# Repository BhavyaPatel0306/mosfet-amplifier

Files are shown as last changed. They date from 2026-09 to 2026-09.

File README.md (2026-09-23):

# MOSFET Amplifier Design



**Four stages. A 3.3 V supply. A study in gain, bandwidth, power, and output headroom.**

An analog electronics project for **ELE404: Electronics I at Toronto Metropolitan University**, built in **KiCad 9** with the supplied NMOS models. Three common-source stages provide voltage gain; a common-drain stage buffers the output.

[Read the report](docs/project-report.pdf) · [Open the design](hardware/ELE404Project.kicad_pro) · [Reproduce the analysis](docs/SIMULATION.md) · [Results and limitations](docs/RESULTS.md)

Current committed KiCad schematic exported with KiCad 9.0.4

*Fresh export of the actual committed circuit. The original report illustrates a different revision; experimental changes are kept in a separate netlist.*

## What this project explores

- **Cascaded voltage gain:** distributing amplification across three common-source stages.
- **Independent DC biasing:** resistor dividers and interstage AC coupling.
- **Load driving:** using a source follower to reduce output impedance.
- **Engineering trade-offs:** balancing low power against output swing and clipping.

```mermaid
flowchart LR
    IN[AC input] --> CS1[Common-source 1]
    CS1 --> CS2[Common-source 2]
    CS2 --> CS3[Common-source 3]
    CS3 --> CD[Source follower]
    CD --> OUT[AC-coupled output]
    OUT --> LOAD[10 kohm / 2 pF load]
```

*Conceptual signal path described in the report; bias and bypass networks are omitted.*

## Fresh simulation evidence

**v0.2.0 includes actual ngspice 44 runs**, raw CSV data, a reproducible runner, and a separate experimental circuit.

- **Original circuit:** 64.82 dB loaded gain, approximately 14.29 MHz upper cutoff, and **1.0208 mW DC power**. Its 1.510 Vpp waveform at 1 mV peak input has **27.91% THD** and clips.
- **Experimental variant:** 61.16 dB loaded gain and **0.9201 mW DC power**. At 0.75 mV peak input it produces **1.568 Vpp with 4.00% THD**.

The variant is a measured improvement at the stated input amplitudes, **not a fully compliant replacement**. Gain-stage overdrive is below the guideline, transient follower current exceeds 200 uA, and clean-swing acceptance still needs a defined distortion limit. The original KiCad circuit is preserved.

Fresh loaded AC comparison

[Measured results and limits](docs/VERIFICATION.md) · [Repeat the runs](simulations/README.md) · [Historical report results](docs/RESULTS.md) · [Versioned releases](https://github.com/BhavyaPatel0306/mosfet-amplifier/releases)

## Get started

1. Download **Code → Download ZIP** and extract it, or clone the repository:

   ```sh
   git clone https://github.com/BhavyaPatel0306/mosfet-amplifier.git
   cd mosfet-amplifier
   ```

2. Open [`hardware/ELE404Project.kicad_pro`](hardware/ELE404Project.kicad_pro) in KiCad 9, then open the schematic.
3. Keep `hardware/models/` alongside the project. All four transistor model references use `models/nmos_t.txt`.
4. Follow the [simulation guide](docs/SIMULATION.md) before running the saved workbook.

**Verification status:** fresh ngspice DC/AC/transient runs and package checks are documented. GitHub Actions checks packaging, not electrical performance. No KiCad GUI/ERC validation or PCB layout validation is claimed; the PCB remains a placeholder.

## Repository guide

```text
mosfet-amplifier/
├── hardware/                 KiCad project, schematic, simulator workbook
│   └── models/               Supplied NMOS and PMOS models
├── docs/
│   ├── project-report.pdf    Original ten-page report
│   ├── design-guidelines.pdf Original assignment specifications
│   ├── SIMULATION.md         Setup and measurement procedure
│   ├── RESULTS.md            Evidence and limitations
│   ├── ROADMAP.md            Prioritized engineering improvements
│   └── images/               Figures extracted from the report
├── simulations/              Portable netlists, raw results, and comparison plots
├── originals/                Untouched project ZIP, including backups
├── scripts/verify_package.py File-integrity and model-reference checks
├── CONTRIBUTING.md           How to submit reproducible improvements
├── RECOVERY.md               Packaging provenance
└── SHA256SUMS.txt            Checksums for distributed files
```

Check the downloaded package with Python 3:

```sh
python scripts/verify_package.py
```

This checks hashes, model references, saved JSON files, and original archive integrity. **It does not simulate the amplifier.**

## Next design steps

The baseline is now simulated and documented. Next, resolve overdrive, distortion, and peak-current constraints before moving an experimental redesign into KiCad. See the [roadmap](docs/ROADMAP.md).

## Source material and reuse

The report, assignment, models, and original archive are preserved from the supplied materials. Images are extracted from that report. No new license has been applied; public visibility does not itself grant reuse rights to third-party course or model materials.

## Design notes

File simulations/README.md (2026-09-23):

# Reproducible circuit study

Two circuits are included: the actual exported KiCad baseline and a separate experimental SPICE variant. The variant is not incorporated into the KiCad schematic and is not a fully compliant replacement.

## Run

Install Python 3.11 or later, the dependencies in `requirements.txt`, and a shared ngspice library. These results used Python 3.12.14, NumPy 2.3.5, and the ngspice 44 DLL bundled with KiCad 9.0.4 on Windows. See `results/summary.json` for the recorded Python version, which is authoritative.

```sh
python -m pip install -r simulations/requirements.txt
python scripts/run_simulations.py --library /path/to/libngspice.so --output build/simulation-results
```

On Windows, the runner detects `C:/Program Files/KiCad/9.0/bin/ngspice.dll` if present. You can also specify `--library` or set `NGSPICE_LIBRARY`. Only the shared-library interface is used; a standalone ngspice executable is not required. No user settings or schematic files are changed by the runner.

The default run uses 27 C, ngspice `ps` compatibility, `reltol=1e-4`, an 80 ms transient with a 200 ns maximum time step, and a 200-point/decade AC sweep from 1 Hz to 100 MHz. It may take several minutes. Results are saved as CSV, JSON, and a simulator log. Plot generation is separate from simulation and is not needed to reproduce numeric results.

## Circuit definitions

- `netlists/baseline.cir`: exported by KiCad 9.0.4 from the committed schematic; only its model include was made relative. The saved source has AC magnitude zero. The runner records that zero-response case, then uses AC magnitude 1 to measure transfer gain. Transient input remains the saved 1 mV peak at 100 kHz.
- `netlists/candidate.cir`: experimental bias/degeneration variant. It adds a 50-ohm source resistor, moves the 2 pF load to the external output, raises R1/R6/R13 to 39 kohm, revises bias dividers, doubles Q3 width to 40 um, and adds a 4.7 kohm unbypassed source resistor at Q4. Input is 0.75 mV peak at 100 kHz.

The baseline gain-stage order is Q1 → Q2 → Q4, followed by follower Q3. This differs from the report's reference designators. Both circuits use the original NMOS model unchanged.

## Measurement definitions

AC output is `Net-_C6-Pad1_`, relative to ground, divided by the source's 1 V AC amplitude. For the candidate this includes the added source resistor. Gain and loaded/unloaded comparison are measured at 100 kHz. The upper cutoff is a 3 dB drop from that reference, interpolated in log frequency.

For the unloaded case, R10 is replaced by 1 Tohm rather than deleted, providing an effectively open DC reference for the output coupling capacitor. All capacitors are retained. Deleting R10 makes the original output float and gives invalid unloaded measurements.

DC power includes the complete supply current. Device current and overdrive are extracted from the internal BSIM transistor (`m.xqN.m0`). Overdrive here means the model's `VGS - VTH`; it is not the model's `VDSAT`. Reported DC branch currents are distinct from transient peak current.

The final 100 us window is compared with the 100 us window 20 ms earlier. THD is the root-sum-square of harmonics 2–10 divided by the fundamental, using a sinusoidal least-squares fit at 100 kHz on a uniformly interpolated trace. This finite-window estimate is not a laboratory distortion measurement or a formal timestep-convergence proof.

## Evidence and limits

Read [the measured results](../docs/VERIFICATION.md). These are fresh simulator runs, but not a claim that every assignment requirement is met. In particular, do not call the experimental waveform distortion-free. Component/process corners, temperature sweeps, GUI/ERC verification, and fabrication checks are outside this release.

The exact netlist, schematic, model, and runner hashes are recorded in `results/summary.json`. Raw data and commands are retained in `results/`. The GitHub Actions workflow checks package integrity and documentation; it does not run ngspice or certify electrical performance.

## References

- [KiCad command-line export documentation](https://docs.kicad.org/9.0/en/cli/cli.html)
- [ngspice shared-library interface](https://ngspice.sourceforge.io/shared.html)

## Regenerate plots

Install `reportlab==4.4.9` and run `python scripts/plot_results.py`. This renders the saved CSV data; it does not rerun ngspice. The simulator logs a missing `spinit` warning in this environment; the runner explicitly sets compatibility and numerical options, and no convergence errors were reported in the saved final run.

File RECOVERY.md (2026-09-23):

# Recovery and validation

The previous `/mnt/data/mosfet-amplifier-github.zip` was unavailable in the current desktop environment. This is a newly reconstructed package from the five recovered conversation attachments, not a byte-for-byte recovery of the missing generated ZIP.

The original project ZIP passed Python zipfile CRC validation. Its complete original bytes are preserved under originals/. Active project files were copied from its top-level project. Only four Sim.Library paths were changed in the active schematic, from an absolute Downloads path to models/nmos_t.txt. Circuit values, project configuration, and workbook analysis settings were not altered. Local locks, preferences, and historical backups are retained only inside the original ZIP.

Both PDFs and model files were copied byte-for-byte. The report and guidelines were inspected by text extraction. No simulation, KiCad GUI opening, electrical-rule check, or PCB validation was performed.

The rebuilt ZIP was checked for CRC errors, extracted into a fresh directory, and every extracted file was compared byte-for-byte to the staged package. A SHA-256 checksum accompanies the downloadable ZIP.

## Repository presentation update

The README and supporting guides were expanded, three historical report figures were extracted, and a Python package verifier was added. Original design files, PDFs, models, and archive are unchanged. The checksum manifest was regenerated for this edition. No new circuit simulations were run.

## v0.2.0 verification update

After the original recovery, fresh ngspice runs were completed. See docs/VERIFICATION.md and simulations/README.md. Earlier statements about no simulations describe the recovery stage only. The original schematic and models remain unchanged; the experimental variant is separate.

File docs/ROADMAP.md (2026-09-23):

# Engineering roadmap

## 1. Establish a reproducible baseline

Fresh runs, exact netlists, raw data, and a runner are now included in v0.2.0. The remaining task is full requirement coverage and model/operating-condition validation.

- Reconcile source settings and sweep range with the original report.
- Run DC, loaded and unloaded AC, and transient analyses with recorded versions and raw data.
- Map each assignment requirement to a measurement definition and result.

Completion means another reader can reproduce measurements from the committed circuit and recorded commands.

## 2. Investigate output swing

A separate variant now demonstrates 1.568 Vpp at 4.00% THD and 0.9201 mW DC power. Resolve its low gain-stage overdrive and transient current before promoting it to the KiCad project.

- Measure headroom, device currents, and clipping onset over input amplitude.
- Define a distortion criterion for acceptable swing.
- Evaluate bias changes and alternative output stages against the 1 mW power and 200 uA branch-current limits.

Completion means demonstrating at least 1.5 Vpp under the specified load and distortion criterion without violating another requirement.

## 3. Test robustness

- Sweep supply and temperature over explicitly selected ranges.
- Explore component and model variation where supported.
- Measure sensitivity to load resistance and capacitance.

Completion means documented sensitivity results and clearly identified supported conditions.

## 4. Consider physical implementation

The PCB is a placeholder. Physical implementation requires a separate technology and component plan, suitable models, layout, and validation. The supplied process-model simulation is not a ready-to-build discrete circuit.

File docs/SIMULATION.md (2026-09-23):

# Reproducing the analysis

Fresh automated runs are available in [VERIFICATION.md](VERIFICATION.md). Use the [reproducible runner](../simulations/README.md) to repeat them. The steps below describe manual inspection in KiCad.

## Open and inspect

1. Use KiCad 9, the version recorded in the schematic header. Other versions have not been tested here.
2. Open `hardware/ELE404Project.kicad_pro`, then its schematic.
3. Confirm the transistor library resolves to `hardware/models/nmos_t.txt` and the selected subcircuit is `nmos_3p3`.
4. Open the simulator and load `hardware/ELE404Project.wbk` if needed. It contains operating-point, AC, and transient setups.
5. Save experiments in a separate working copy or branch. Record KiCad and ngspice versions with the results.

## Known differences

The report and supplied project are not demonstrably the same simulation revision:

- The saved source is V2 with value `SINE(0 1m 100k)` and `Sim.Params` of `ac=0`. The report schematic shows V5, 1.45 mV peak at 100 kHz, and `ac=1`.
- The saved AC sweep is `.ac dec 100 1 10Meg`. The report describes 1 kHz to 100 MHz. A 10 MHz endpoint cannot establish a 20 MHz upper cutoff.
- The saved transient setup is `.tran 50n 100u 0 50n`. Confirm settling before measuring; extend the run if coupling or bypass capacitor startup is still visible.
- Saved traces refer to auto-generated node names. Check that each still maps to the intended input, interstage, or output node.

Reconcile these differences explicitly before claiming the report is reproduced. Original circuit settings have been preserved.

## DC operating point

Run `.op`. Record gate, drain, source, and bulk voltages, branch currents, and supply current. Check operating regions using actual model operating-point data where available. Calculate total power from supply voltage and current, accounting for the simulator's sign convention and including divider currents.

Compare against the guideline limits: 3.3 V supply, at most 1 mW total DC power, and at most 200 uA per branch.

## AC gain and bandwidth

Configure a nonzero small-signal AC magnitude, such as 1 V, in the source model editor. This AC normalization is separate from the small transient input amplitude.

Sweep beyond the expected cutoff; the report used 1 kHz to 100 MHz. Measure `V(out)/V(in)` and specify where input voltage is measured relative to the 50-ohm source resistor. Keep that definition consistent.

Find midband gain and the upper frequency where gain has dropped 3 dB from midband. Do not confuse this with an absolute gain of -3 dB. Extend the lower sweep when assessing the coupling-capacitor cutoff.

## Load sensitivity

Save separate loaded and unloaded configurations. State exactly which load elements change; the specified load is 10 kohm in parallel with 2 pF. Hold source settings, bias, and measurement frequency constant.

```text
gain reduction (%) = 100 × (1 − |A_loaded| / |A_unloaded|)
                   = 100 × (1 − 10^((G_loaded_dB − G_unloaded_dB)/20))
```

Do not calculate voltage-gain sensitivity by dividing a difference in dB by a dB value.

## Transient output swing

Start with a small sinusoid and sweep amplitude while staying within the 10 mVpp input limit. The report used 1.45 mV peak, or 2.9 mVpp, at 100 kHz.

After settling, inspect input and output, record output extrema, and check for flattened peaks or asymmetric clipping. Define a distortion criterion before calling the swing clean. A peak-to-peak measurement alone does not establish linear operation.

## Save reproducible evidence

Retain circuit revision, source settings, commands, simulator versions, load configuration, measurement definitions, raw exported data, and plots. Report failures and discrepancies alongside successful measurements.

See [RESULTS.md](RESULTS.md) for historical values and [ROADMAP.md](ROADMAP.md) for next steps.

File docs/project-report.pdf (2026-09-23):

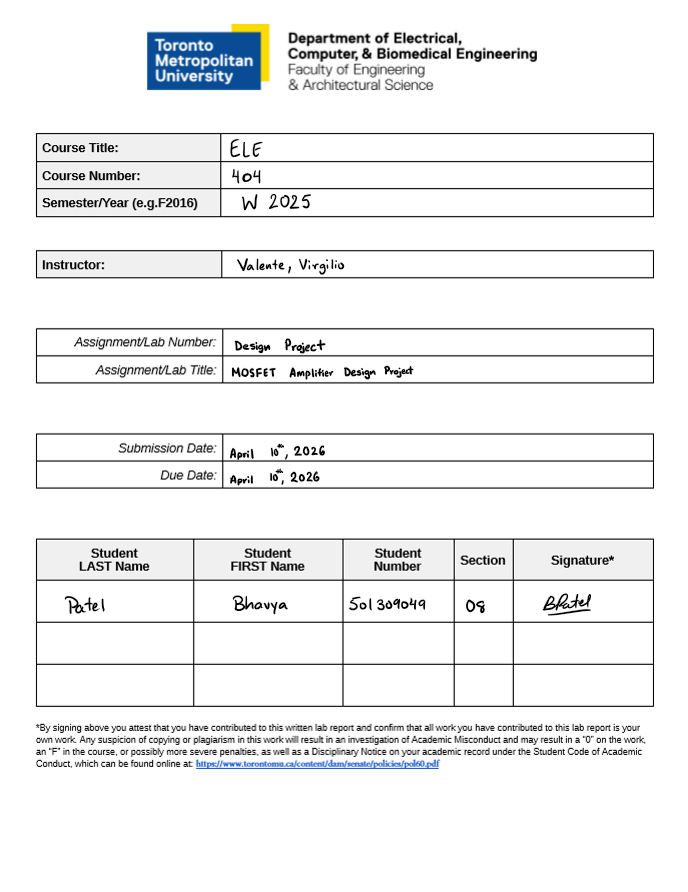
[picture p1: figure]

Introduction

This report details the design and simulation of an all-MOSFET, open-loop analog voltage amplifier developed using the Global Foundries 180nm CMOS process. To satisfy the project requirements, the circuit is engineered to deliver a minimum total voltage gain of 60 dB, a -3 dB bandwidth exceeding 500 kHz, and a maximum DC power consumption of 1 mW. The architecture consists of four NMOS transistor stages, featuring three cascaded Common-Source (CS) amplifiers for high gain followed by a Common-Drain (CD) source follower. This final stage acts as an output buffer, ensuring the amplifier can drive a 10 kΩ load without significant gain degradation.

Architecture Justification

The amplifier is constructed from four distinct NMOS stages designed to meet specific performance targets. The first stage (Q2) utilizes a Common-Source configuration to provide initial voltage gain; it incorporates a 280 kΩ bias divider network to exceed the 100 kΩ input resistance requirement and a 100 nF capacitor for AC coupling to block DC signals. The second (Q1) and third (Q3) stages are also AC-coupled Common-Source amplifiers cascaded to incrementally boost the signal until the total voltage gain reaches the target of at least 60 dB. Finally, the fourth stage (Q4) serves as a Common-Drain source follower that acts as an output buffer. While this final stage offers near-unity gain, its primary function is to significantly lower the output resistance, thereby isolating the preceding gain stages from the load and ensuring that gain reduction remains below 10% when driving a 10 kΩ load.

The selection of specific transistor topologies was driven by the need to balance high gain with effective load driving capabilities. The CS configuration was chosen for the first three stages because it offers superior voltage gain compared to other MOSFET setups. With a gain defined by |Av| = gm x (RD || ro), each stage contributes approximately 20–30 dB; when cascaded, these stages cumulatively reach the 60 dB target while remaining within the project's power and headroom limits.

For the final output stage, a Common-Drain (source follower) was implemented to provide a low output resistance, roughly equal to 1/gm. Although its voltage gain is slightly below unity (calculated at 0.71 V/V for this specific design), its low impedance is vital for driving the 10 kΩ load. This buffering effect minimizes the load's impact on the overall circuit, resulting in a load sensitivity of just 1.54%, which comfortably exceeds the maximum allowable 10% gain reduction specification.

All stage gains are below 40 dB, satisfying the per-stage gain constraint:

Stage | Transitor | Topology | Gain (V/V) | Gain dB
1 | Q2 | CS | 13.7 | 22.7
2 | Q1 | CS | 22.3 | 26.9

3 | Q3 | CS | 13.7 | 22.7
4 | Q4 | CD | 0.71 | -3.0

Calculations

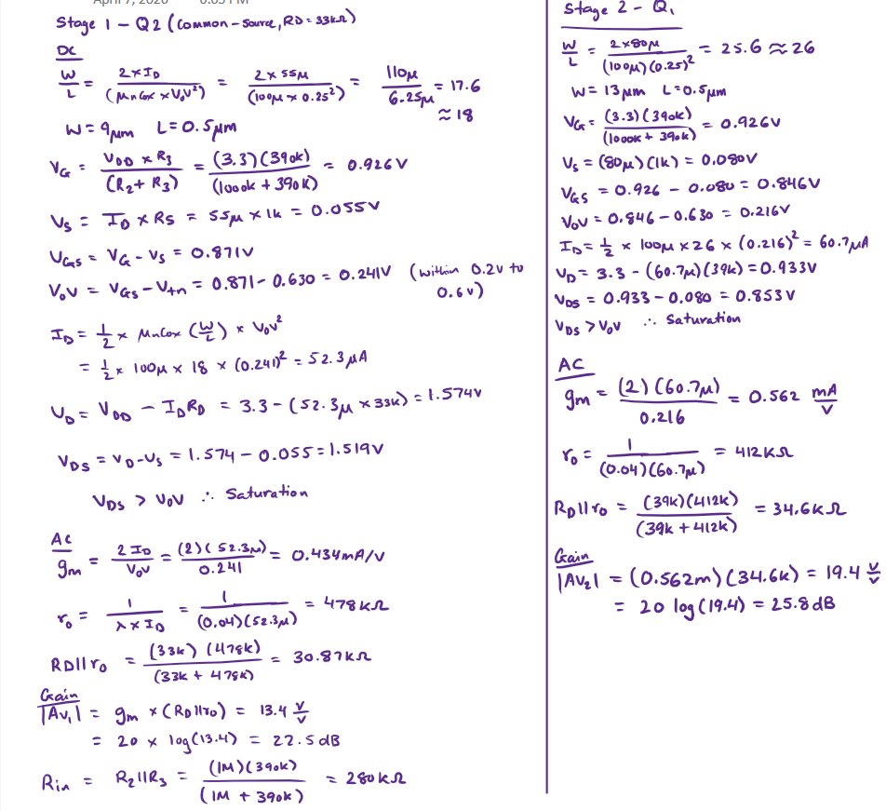
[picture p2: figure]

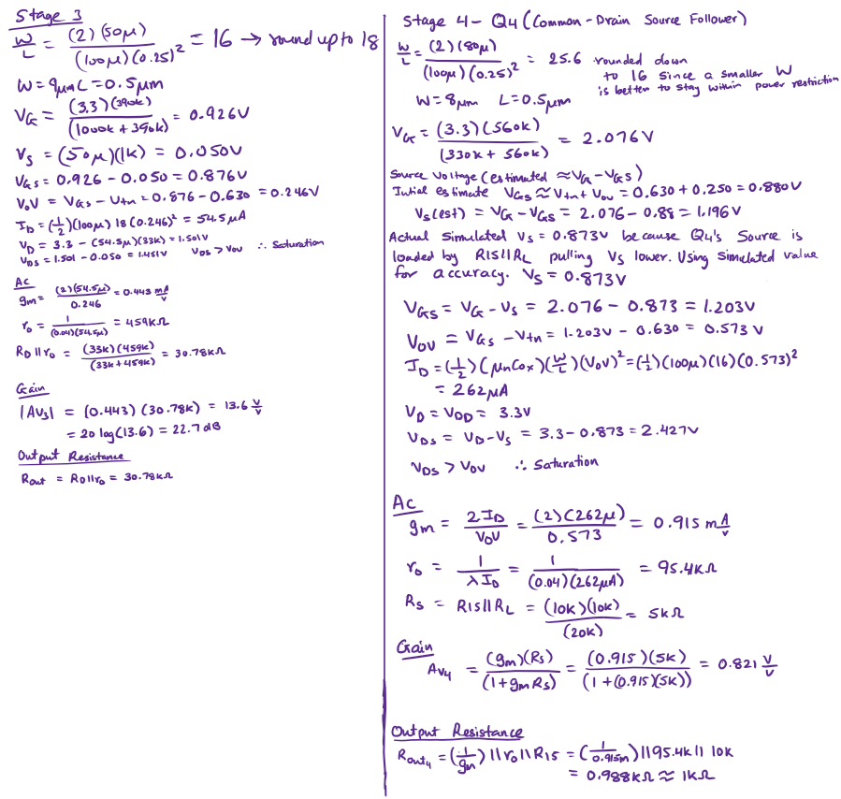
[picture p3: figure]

Biasing Strategy

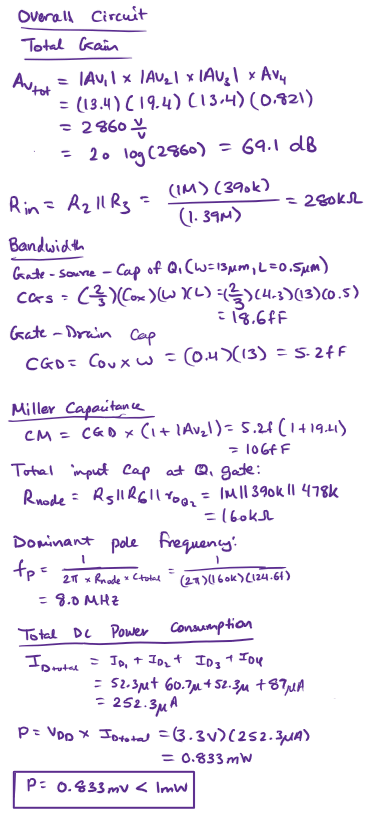
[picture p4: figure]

The biasing strategy for each Common-Source stage involves a resistor voltage divider to set a stable DC gate voltage, providing robustness against temperature and process shifts. To further enhance DC stability, a 1 kΩ source resistor (RS) is used to implement negative feedback. To prevent this resistor from causing source degeneration and lowering the AC voltage gain, a large 10 uF electrolytic bypass capacitor is added, effectively creating an AC short to ground. Furthermore, 100 nF AC coupling capacitors are utilized between stages to isolate DC bias levels; this allows each stage to be biased independently while ensuring the signal passes through the entire chain unimpeded.

Simulation Results

Schematic

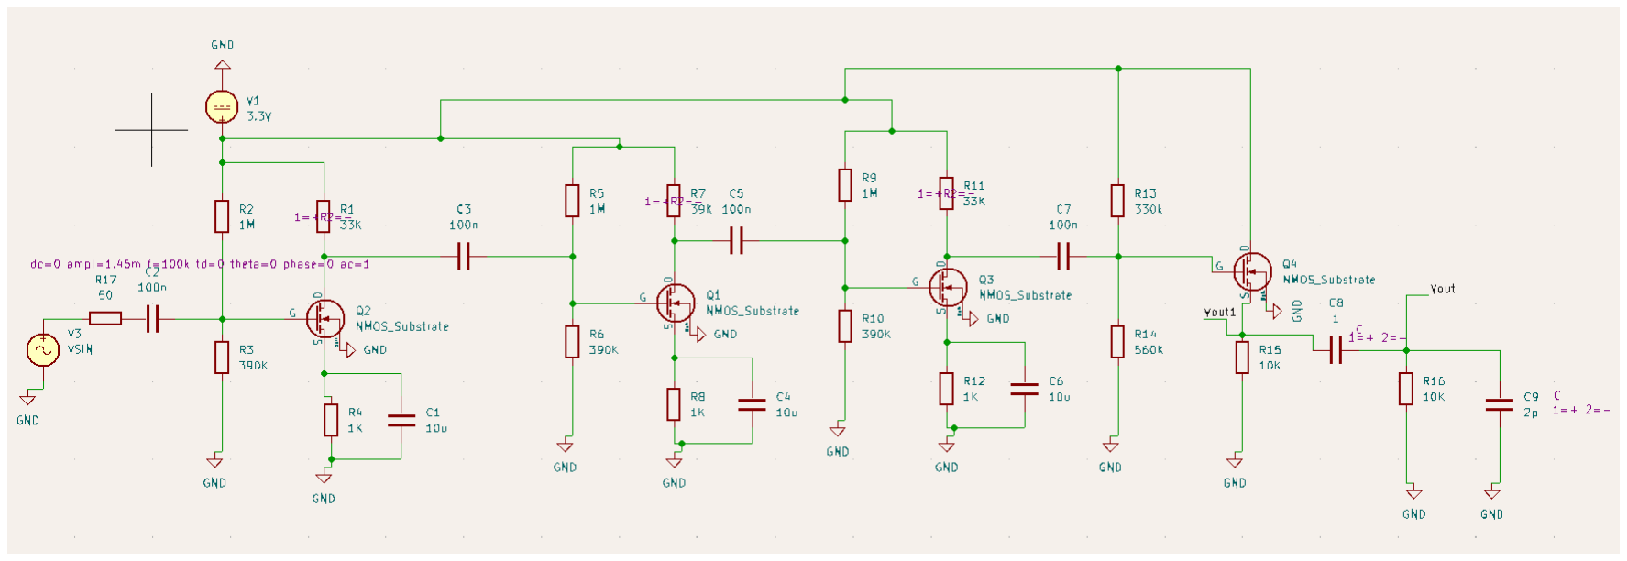
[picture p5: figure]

DC Operating Point

The DC operating point simulation was run to verify that all transistors are properly biased in the saturation region.

Transistor | VG (V) | VS(V) | VD(V) | VGS(V) | VDS(V)
Q2 | 0.926 | 0.048 | 1.729 | 0.878 | 1.681
Q1 | 0.926 | 0.058 | 1.044 | 0.868 | 0.986
Q3 | 0.926 | 0.048 | 1.729 | 0.878 | 1.681
Q4 | 2.076 | 0.873 | 3.300 | 1.203 | 2.427

To ensure proper linear amplification, every transistor in the design is biased within the saturation region, with the condition VDS > VOV confirmed for each device. The circuit draws a total supply current of 251 uA, resulting in an overall DC power dissipation of 0.828 mW. This performance figure successfully meets the project requirement of remaining under the 1 mW power limit.

AC Analysis

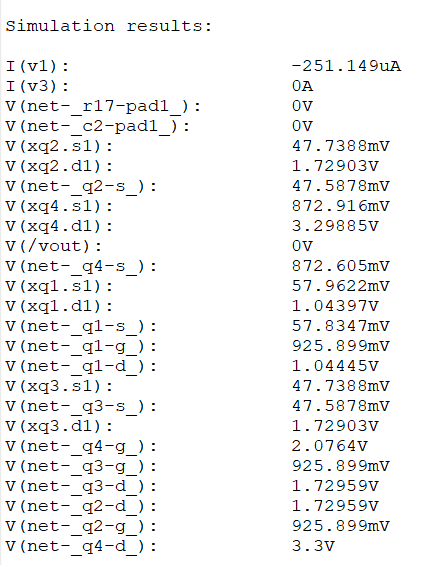
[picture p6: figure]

The AC small-signal analysis was performed with a frequency sweep from 1kHz to 100MHz (100 points per decade). The Bode plot of V(Vout)/V(Vin) in dB is shown below.

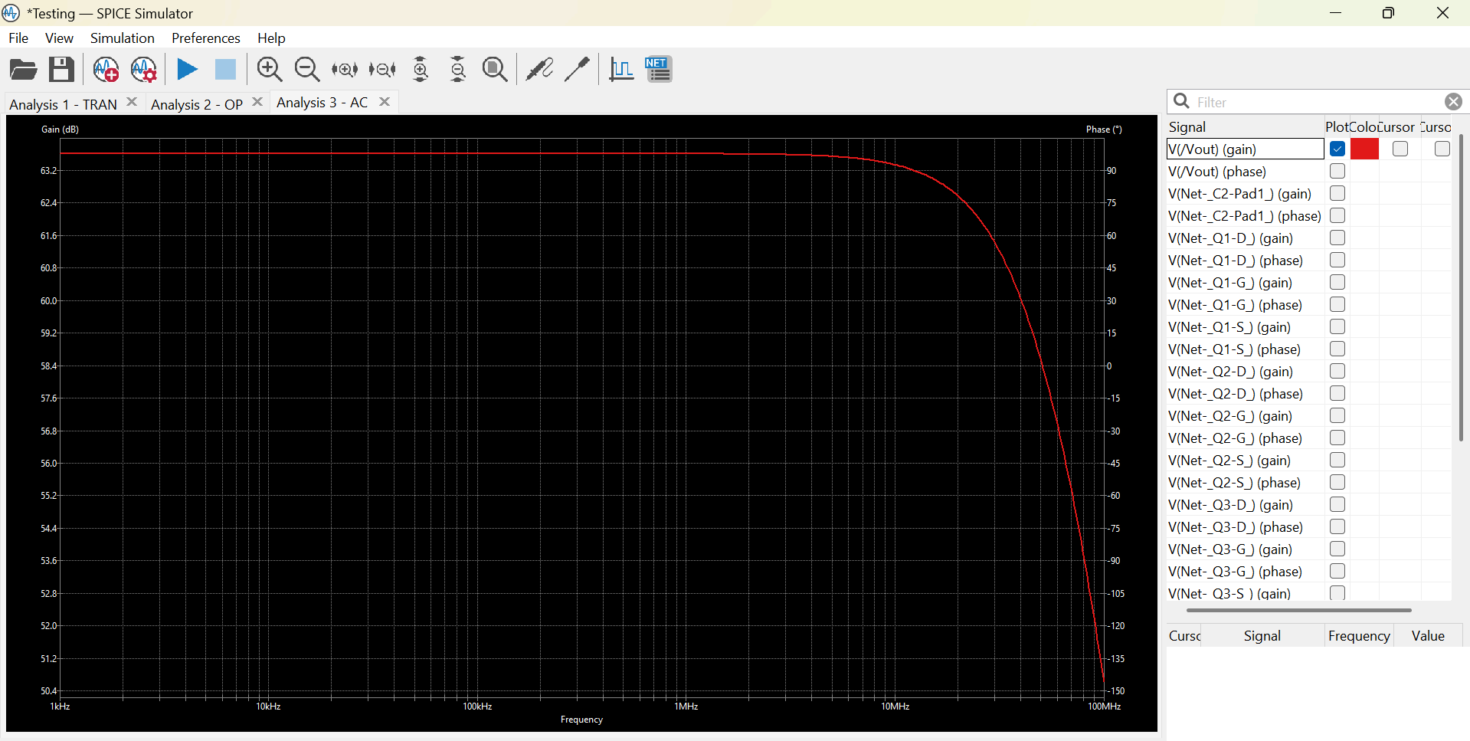
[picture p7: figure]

Parameter | Simulated Result
Midband gain (loaded) | 63.8 dB
Midband gain (unloaded) | 64.6 dB
-3 db Bandwidth | 20 MHz

Load Sensitivity | 1.54 % (dB)

The amplifier achieves a loaded midband gain of 63.8 dB, which comfortably surpasses the 60 dB design goal. Additionally, the -3 dB bandwidth reaches approximately 20 MHz, providing a substantial performance margin by exceeding the 500 kHz minimum requirement by a factor of 40. The unloaded gain was measured at 64.6 dB, indicating a load sensitivity of roughly 1.54%, a result that is well within the maximum allowable 10% specification.

Transient Analysis - Output Swing

A transient simulation was performed with a 100 kHz sinusoidal input of amplitude 1.45 mV (2.9 mVpp) to verify the output voltage swing.

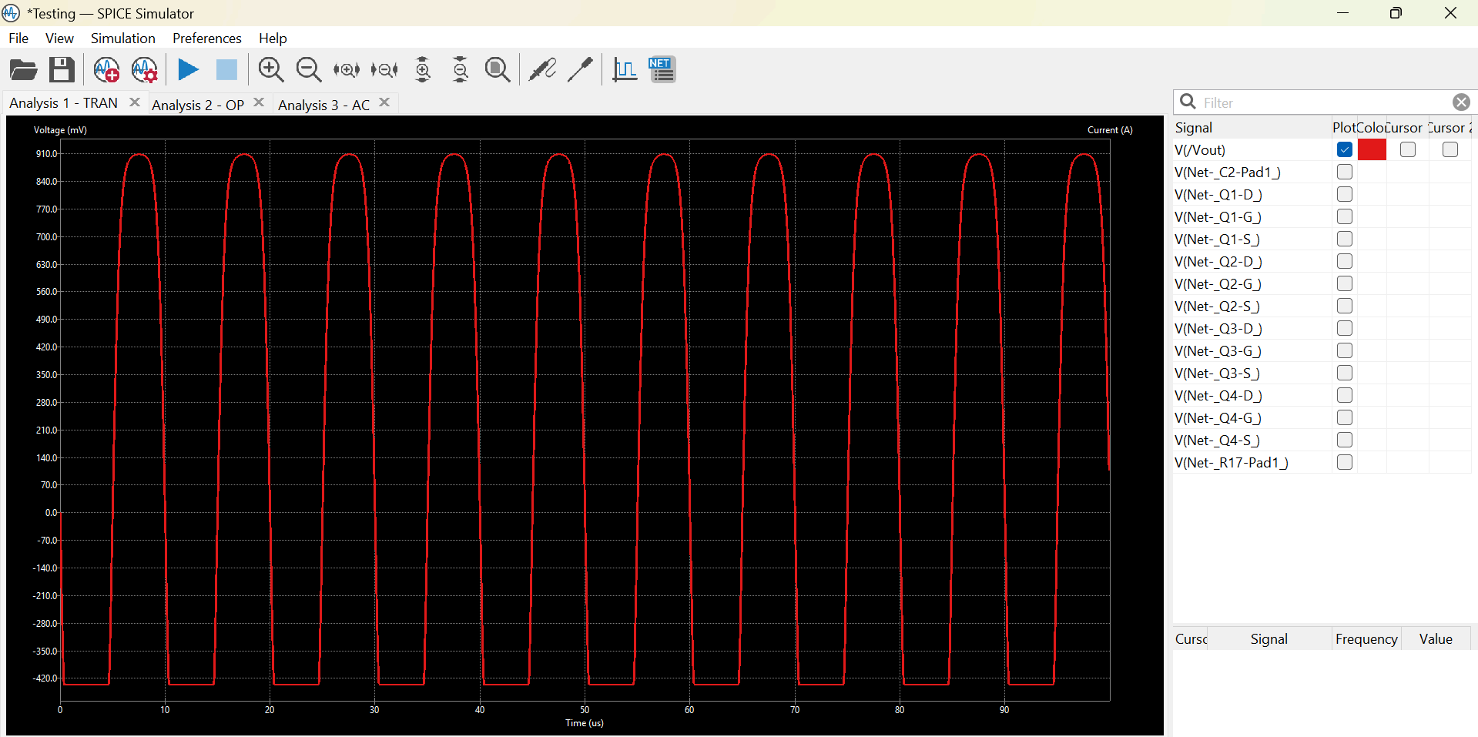
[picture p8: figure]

The output waveform demonstrates clear sinusoidal amplification. The positive half-cycle swings to +910 mV while the negative half-cycle is limited to approximately -420 mv before clipping occurs which makes the peak-to-peak swing to 1.33 Vpp.

Hand Calculations Vs Simulation

The hand calculations provide a reasonable first-order estimate of the circuit behaviour, with discrepancies in the expected range of 10-20% as stated in the design guidelines.

Parameter | Hand Calculation | Simulation | Discrepancy
Gate Voltage VG (Q2, Q3) | 0.926 V | 0.926 V | 1%
Drain Voltage VD (Q2,Q3) | 1.47 V | 1.729 V | 15%
Drain Current ID (Q2,Q3) | 55.4 uA | 52 uA | 6%
Total Gain | 69.5 dB | 63.8 dB | 8%

The gate voltage exhibits nearly perfect alignment because it is determined solely by the resistor divider network. However, the drain voltage shows a 15% discrepancy, which remains within expected limits; this variance arises because the simplified theoretical model does not account for second-order effects like the body effect and channel length modulation. Similarly, a total gain deviation of roughly 8% is observed, primarily due to inter-stage loading. While hand calculations typically treat each stage as an isolated entity, the physical cascading of these stages introduces finite output resistances that load subsequent stages, ultimately lowering the overall effective gain.

Output Swing

The simulation revealed that the output swing goal of 1.5 Vpp was not fully achieved, peaking at a clean maximum of approximately 1.33 Vpp. This shortfall is characterized by asymmetric clipping where the positive peak is larger than the negative, a common limitation of single-supply Common-Drain topologies. While the transistor Q4 can actively pull the output voltage up, it relies on the passive pull-down resistor (R15) to discharge the output node. During negative swings, as VGS approaches the threshold voltage, Q4 begins to cut off, leaving the parallel combination of R15 and RL (5 kΩ effective) unable to discharge the output capacitance quickly enough at 100 kHz.

To achieve a symmetric 1.5 Vpp swing, several design enhancements could be considered:

- Active Sourcing: Replace the passive resistor R15 with an active current source, such as a diode-connected NMOS, to improve sinking capability.
- Push-Pull Configuration: Transition to a CMOS push-pull output stage using complementary NMOS and PMOS transistors for balanced drive.
- Bias Adjustment: Shift the gate bias voltage of Q4 closer to the mid-rail to increase available headroom for both halves of the signal swing.

The design's total DC power consumption of 0.828 mW (at a total current of 251 µA) successfully meets the 1 mW limit with a 17% safety margin. Individual branch currents remained well under the 200 µA maximum, with Q1 drawing the highest current at approximately 80 µA. Ultimately, the strict power budget was the primary constraint limiting the drain bias current and, consequently, the maximum achievable transconductance (gm) in each stage.

Several design trade-offs were managed:
- Transistor Sizing: While increasing the transistor width (W) boosts gm and voltage gain, it simultaneously raises the drain current (ID), which increases power consumption and reduces drain voltage headroom. W values were specifically selected to balance these competing factors.
- Drain Resistance: The selection of drain resistors (RD) impacts both the DC operating point (VD = VDD - ID x RD) and AC gain (|Av| = gm x RD). Larger RD values enhance gain but lower VD, which restricts the output swing. The chosen values (33 kΩ for Q2/Q3 and 39 kΩ for Q1) reflect a calculated compromise to maintain high gain without sacrificing necessary voltage headroom.

Conclusion

A four-stage MOSFET voltage amplifier was successfully developed and simulated using the Global Foundries 180nm CMOS process. By cascading three Common-Source stages with a final Common-Drain source follower, the design achieved a loaded gain of 63.8 dB and an unloaded gain of 64.8 dB, both of which surpass the 60 dB target. Performance in other areas was also strong: the 20 MHz bandwidth far exceeded the 500 kHz minimum, and the total DC power consumption of 0.828 mW remained well under the 1 mW limit.

The only specification not entirely met was the output swing; the design produced a clean, undistorted output of 1.33 Vpp against the 1.5 Vpp requirement. This shortfall is attributed to the asymmetric drive limitations of a passive source follower output stage. To reach the full 1.5 Vpp target, replacing the pull-down resistor (R15) with an active current source is recommended.

Finally, manual calculations aligned with simulation results within a 10-20 range. The minor discrepancies primarily resulted from inter-stage loading and the use of simplified single-pole models for bandwidth estimation. Ultimately, this project illustrates the essential trade-offs between gain, bandwidth, power efficiency, and output swing inherent in MOSFET amplifier design.

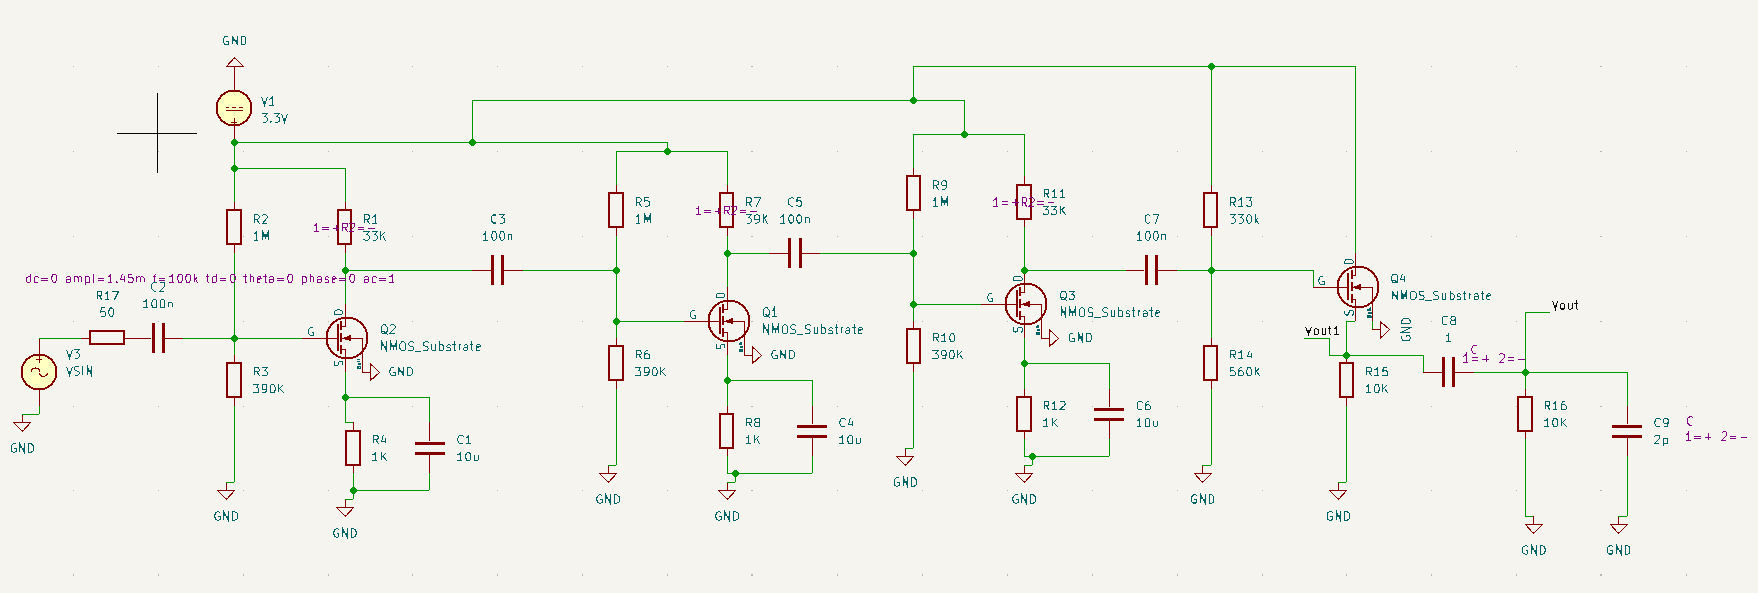
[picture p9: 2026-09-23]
docs/images/reported-schematic.png

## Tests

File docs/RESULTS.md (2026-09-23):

# Results, evidence, and limitations

**Fresh runs are now available:** see [v0.2.0 verification](VERIFICATION.md) and [raw results](../simulations/results/summary.json). The remainder of this page describes the historical report.

## Evidence boundary

The [original report](project-report.pdf) contains the author's simulation discussion and screenshots. Fresh runs of the supplied circuit give different results; see the verification link above. The [guidelines](design-guidelines.pdf) define the targets. Both PDFs remain unchanged.

## Historical report values

- **Loaded gain:** 63.8 dB, report page 7.
- **Unloaded gain:** 64.6 dB, page 7; target at least 60 dB.
- **Upper -3 dB bandwidth:** approximately 20 MHz, page 7; target at least 500 kHz. The current saved sweep stops at 10 MHz, so a new run needs a wider range.
- **DC power:** 0.828 mW at a reported 251 uA total current, page 6; limit 1 mW.
- **Output swing:** approximately 1.33 Vpp, pages 8–9; target at least 1.5 Vpp. The figure shows clipping, so it does not establish a clean 1.33 Vpp swing.

Other requirements, including input resistance, per-stage gain, sizing, overdrive, and maximum branch current, require consistent fresh verification before claiming full compliance.

## Load-sensitivity correction

The report lists 1.54% load sensitivity. Percent voltage-gain reduction must use linear gains, not percentage changes in dB values. From the rounded reported gains:

```text
100 × (1 − 10^((63.8 − 64.6)/20)) ≈ 8.80%
```

This is arithmetic on reported numbers, not a new measurement. It is below the 10% limit if the gains are reproduced under comparable conditions.

## Output-stage limitation

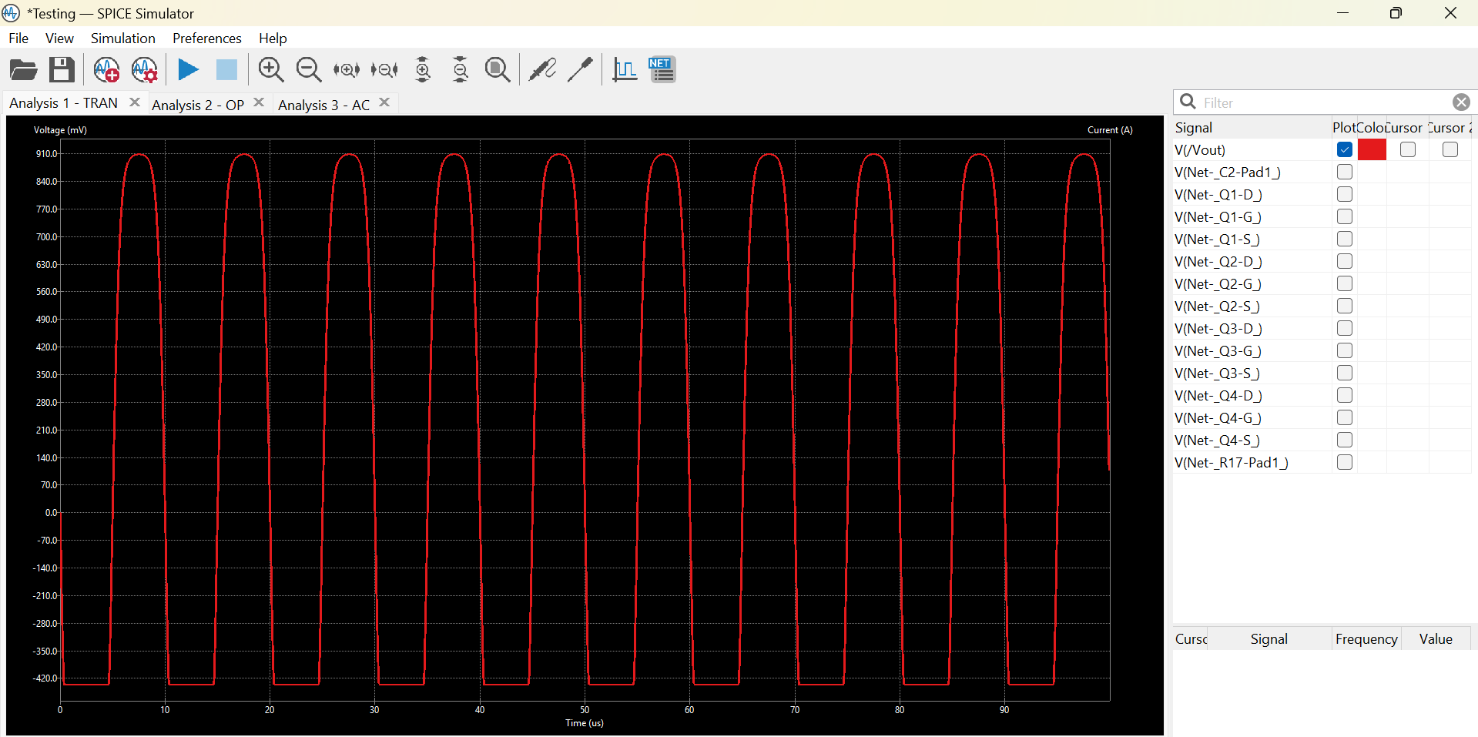
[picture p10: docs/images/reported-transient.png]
Transient plot from report page 8 showing asymmetric clipping


The output has a flattened negative excursion. Investigate device operating points and transient currents before selecting a redesign. The existing evidence does not establish a distortion-qualified output swing.

## Figure provenance

- `images/reported-schematic.png`: embedded schematic, report page 6.
- `images/reported-ac-response.png`: embedded AC plot, report page 7.
- `images/reported-transient.png`: embedded transient plot, report page 8.

Figures were extracted without redrawing the circuit or regenerating curves. They show the report revision, which differs from the supplied project in source settings and sweep range. See [SIMULATION.md](SIMULATION.md#known-differences).

## Verification scope

File hashes, original ZIP CRC, relative model references, and KiCad project/workbook JSON parsing are package checks. They do not demonstrate circuit correctness, model compatibility, fabrication readiness, or simulation success by themselves. The separately documented ngspice runs provide the fresh simulation evidence.

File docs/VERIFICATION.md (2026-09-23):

# Fresh simulation results — v0.2.0

These results were actually run with **ngspice 44**, using a **KiCad 9.0.4 export** and the supplied model files. They supersede assumptions that the original report describes the committed circuit. Full settings, hashes, CSV data, and logs are available in [simulations/](../simulations/README.md).

## Original KiCad circuit

- DC supply power: **1.0208 mW**, above the **1 mW** maximum.
- Gain at 100 kHz: **64.82 dB loaded**, **65.67 dB unloaded** with a 1 Tohm DC output reference.
- Upper cutoff relative to the 100 kHz gain: approximately **14.29 MHz**.
- Load-related voltage-gain reduction: approximately **9.34%**.
- At the saved **1 mV peak, 100 kHz** input: approximately **1.510 Vpp**, with **27.91% THD** over harmonics 2–10. This is clipped output, not a successful clean-swing result.
- Follower drain-current peak in the final transient window: approximately **288 uA**; its minimum approaches zero, consistent with cutoff.

The saved AC source magnitude is **zero** and produces zero AC response. Only the AC transfer-function measurement overrides it to 1. The original schematic is preserved.

The baseline also lacks the specified 50-ohm input source resistor and places its 2 pF capacitor before the output coupling capacitor. Its gain-stage overdrives, using model VGS minus VTH, are approximately **0.045 V, 0.144 V, and 0.144 V**, below the guideline's 0.2 V lower bound.

## Experimental variant

- DC supply power: **0.9201 mW**.
- Gain at 100 kHz: **61.16 dB loaded**, **61.69 dB unloaded**.
- Upper cutoff relative to the 100 kHz gain: approximately **11.02 MHz**.
- Load-related voltage-gain reduction: approximately **5.91%**.
- At **0.75 mV peak, 100 kHz** input: approximately **1.568 Vpp**, with **4.00% THD** over harmonics 2–10.
- Follower current remains above zero in the sampled final window, but peaks near **307 uA**.

This variant improves nominal power and reduces distortion at the stated test amplitudes. The comparison is not at identical input amplitudes. It remains **experimental**: its gain-stage overdrives are approximately **0.077–0.079 V**, below the 0.2 V guideline. Its transient current also exceeds 200 uA; only its DC branch currents are below that number. Until the branch-current interpretation and other requirements are resolved, it must not be called fully compliant.

The assignment does not specify a THD threshold. Reporting 1.568 Vpp therefore does not establish an acceptable clean swing. A stricter 1% THD criterion would fail at this operating point.

Loaded AC response measured from the baseline and experimental netlists

Fresh transient comparison at the stated, different input amplitudes

## Settling check

The default transient runs to 80 ms and compares the last 100 us with a 100 us window 20 ms earlier. Output Vpp changed by approximately **−0.137% for the baseline** and **+0.0077% for the variant**. This suggests modest residual drift at the measured windows; it is not a proof of convergence for every quantity or every operating condition.

## What changed and what did not

The committed KiCad schematic, transistor models, original PDFs, and original ZIP remain unchanged. The current schematic preview is a fresh export with a tighter viewport. All experimental circuit changes exist only in `simulations/netlists/candidate.cir` and are listed in the [run guide](../simulations/README.md).

No claim is made about measured hardware performance, manufacturing readiness, temperature/process corners, or complete assignment compliance. Further transistor sizing and bias work is required before promoting the candidate into the KiCad design.

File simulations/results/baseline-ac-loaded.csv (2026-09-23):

frequency_hz | vout_real_v | vout_imag_v
1 | -0.6744860957 | -0.2541260929
1.011579454 | -0.7152266639 | -0.2587028343
1.023292992 | -0.7582498178 | -0.2628432019
1.035142167 | -0.8036678386 | -0.2664779194
1.047128548 | -0.8515971564 | -0.2695313752
1.059253725 | -0.9021583766 | -0.2719211757
1.071519305 | -0.9554762922 | -0.2735576771
1.083926914 | -1.01167988 | -0.2743434916
1.096478196 | -1.070902278 | -0.2741729688
1.109174815 | -1.133280744 | -0.2729316532
1.122018454 | -1.198956595 | -0.2704957143
1.135010816 | -1.268075116 | -0.266731352
1.148153621 | -1.340785446 | -0.2614941745
1.161448614 | -1.41724044 | -0.2546285507
1.174897555 | -1.49759649 | -0.2459669356
1.188502227 | -1.58201332 | -0.2353291685
1.202264435 | -1.670653739 | -0.2225217466
1.216186001 | -1.763683355 | -0.2073370706
1.230268771 | -1.86127025 | -0.1895526665
1.244514612 | -1.963584599 | -0.1689303822
1.258925412 | -2.070798252 | -0.14521556
1.273503081 | -2.183084249 | -0.1181361872
1.288249552 | -2.300616291 | -0.08740202508
1.303166778 | -2.423568137 | -0.05270371875
1.318256739 | -2.552112949 | -0.01371188916
1.333521432 | -2.68642256 | 0.02992378991
1.348962883 | -2.826666675 | 0.07857552755
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

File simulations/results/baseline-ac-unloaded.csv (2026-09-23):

frequency_hz | vout_real_v | vout_imag_v
1 | -4.788502536 | 10.45447764
1.011579454 | -4.859149267 | 10.96753351
1.023292992 | -4.924408119 | 11.50330429
1.035142167 | -4.983593116 | 12.06260942
1.047128548 | -5.03596963 | 12.64628365
1.059253725 | -5.080751941 | 13.25517601
1.071519305 | -5.117100724 | 13.89014879
1.083926914 | -5.144120481 | 14.5520763
1.096478196 | -5.160856911 | 15.24184352
1.109174815 | -5.166294227 | 15.96034458
1.122018454 | -5.159352425 | 16.70848104
1.135010816 | -5.138884509 | 17.48716006
1.148153621 | -5.103673679 | 18.29729229
1.161448614 | -5.052430489 | 19.13978967
1.174897555 | -4.983789985 | 20.01556292
1.188502227 | -4.896308832 | 20.92551888
1.202264435 | -4.788462433 | 21.8705576
1.216186001 | -4.658642058 | 22.85156918
1.230268771 | -4.505151999 | 23.86943039
1.244514612 | -4.326206753 | 24.92500105
1.258925412 | -4.119928248 | 26.01912006
1.273503081 | -3.884343137 | 27.15260127
1.288249552 | -3.617380172 | 28.32622901
1.303166778 | -3.316867663 | 29.5407533
1.318256739 | -2.980531064 | 30.79688484
1.333521432 | -2.605990679 | 32.09528966
1.348962883 | -2.190759535 | 33.43658346
1.364583137 | -1.732241422 | 34.82132563
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

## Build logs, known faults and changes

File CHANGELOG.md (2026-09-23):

# Changelog

## 0.2.0

- Export the actual committed KiCad schematic and a portable baseline SPICE netlist.
- Add fresh DC, AC, loaded/unloaded, and long-transient ngspice results with raw CSV data, logs, model/device measurements, and source hashes.
- Add a separate experimental bias/degeneration variant; document both its improvements and remaining failures.
- Add reproducible simulation and release-building scripts.
- Add GitHub Actions checks for hashes, documentation links, result metadata, and release packaging.
- Preserve all original design and source materials.

This release establishes reproducible evidence, not full design compliance. The original circuit exceeds the DC power limit and clips. The variant improves power and distortion but still has overdrive and transient-current limitations.

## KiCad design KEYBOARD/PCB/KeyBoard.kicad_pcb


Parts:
A1: RaspberryPi_Pico; RaspberryPi_Pico_Common_Unspecified
D1, D2, D3, D4, D5, D6, D7, D8, D9, D10, D11, D12, D13, D14, D15, D16, D17, D18, D19, D20, D21, D22, D23, D24, D25, D26, D27, D28, D29, D30, D31, D32, D33, D34, D35, D36, D37, D38, D39, D40, D41, D42, D43, D44, D45, D46, D47, D48, D49, D50, D51, D52, D53, D54, D55, D56, D57, D58, D59, D60, D61: 1N4148; D_DO-35_SOD27_P7.62mm_Horizontal
S1: MX_stab; STAB_MX_2u
S2, S3: MX_stab; STAB_MX_2.25u
S4: MX_stab; STAB_MX_2.75u
S5: MX_stab; STAB_MX_6.25u
SW1, SW2, SW3, SW4, SW5, SW6, SW7, SW8, SW9, SW10, SW11, SW12, SW13, SW16, SW17, SW18, SW19, SW20, SW21, SW22, SW23, SW24, SW25, SW26, SW27, SW30, SW31, SW32, SW33, SW34, SW35, SW36, SW37, SW38, SW39, SW40, SW51, SW52, SW53, SW54, SW55, SW56, SW57, SW58, SW59, SW60: SW_Push; SW_Cherry_MX_1.00u_PCB
SW14: SW_Push; SW_Cherry_MX_2.00u_PCB
SW15: SW_Push; SW_Cherry_MX_1.50u_PCB
SW28: SW_Push; SW_Cherry_MX_1.50u_Plate
SW29: SW_Push; SW_Cherry_MX_1.75u_PCB
SW41, SW50: SW_Push; SW_Cherry_MX_2.25u_PCB
SW42, SW43, SW44, SW46, SW48, SW49: SW_Push; SW_Cherry_MX_1.25u_PCB
SW45: SW_Push; SW_Cherry_MX_6.25u_PCB
SW47: SW_Push; SW_Cherry_MX_1.25u_Plate
SW61: SW_Push; SW_Cherry_MX_2.75u_PCB
SW62, SW63: RotaryEncoder_Switch_MP; RotaryEncoder_Alps_EC11E-Switch_Vertical_H20mm

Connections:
A1: A1.27 (GPIO21), SW62.A
A2: A1.32 (GPIO27_ADC1), SW63.A
B1: A1.29 (GPIO22), SW62.B
B2: A1.34 (GPIO28_ADC2), SW63.B
C0: A1.10 (GPIO7), SW1.1, SW15.1, SW29.1, SW42.1, SW50.1
C1: A1.11 (GPIO8), SW2.1, SW16.1, SW30.1, SW43.1, SW51.1
C2: A1.12 (GPIO9), SW3.1, SW17.1, SW31.1, SW44.1, SW52.1
C3: A1.14 (GPIO10), SW4.1, SW18.1, SW32.1, SW53.1
C4: A1.15 (GPIO11), SW5.1, SW19.1, SW33.1, SW54.1
C5: A1.16 (GPIO12), SW6.1, SW20.1, SW34.1, SW45.1, SW55.1
C6: A1.17 (GPIO13), SW7.1, SW21.1, SW35.1, SW56.1
C7: A1.19 (GPIO14), SW8.1, SW22.1, SW36.1, SW57.1
C8: A1.20 (GPIO15), SW9.1, SW23.1, SW37.1, SW46.1, SW58.1
C9: A1.21 (GPIO16), SW10.1, SW24.1, SW38.1, SW47.1, SW59.1
C10: A1.22 (GPIO17), SW11.1, SW25.1, SW39.1, SW48.1, SW60.1
C11: A1.24 (GPIO18), SW12.1, SW26.1, SW40.1, SW49.1, SW61.1
C12: A1.25 (GPIO19), SW13.1, SW27.1, SW41.1
C13: A1.26 (GPIO20), SW14.1, SW28.1
GND: A1.33 (AGND), SW62.C, SW62.S2, SW63.C, SW63.S2
unnamed: A1.3 (GND), A1.8 (GND), A1.13 (GND), A1.18 (GND), A1.23 (GND), A1.28 (GND), A1.38 (GND)
unnamed: D1.2 (A), SW1.2
unnamed: D2.2 (A), SW2.2
unnamed: D3.2 (A), SW3.2
unnamed: D4.2 (A), SW4.2
unnamed: D5.2 (A), SW5.2
unnamed: D6.2 (A), SW6.2
unnamed: D7.2 (A), SW7.2
unnamed: D8.2 (A), SW8.2
unnamed: D9.2 (A), SW9.2
unnamed: D10.2 (A), SW10.2
unnamed: D11.2 (A), SW11.2
unnamed: D12.2 (A), SW12.2
unnamed: D13.2 (A), SW13.2
unnamed: D14.2 (A), SW14.2
unnamed: D15.2 (A), SW15.2
unnamed: D16.2 (A), SW16.2
unnamed: D17.2 (A), SW17.2
unnamed: D18.2 (A), SW18.2
unnamed: D19.2 (A), SW19.2
unnamed: D20.2 (A), SW20.2
unnamed: D21.2 (A), SW21.2
unnamed: D22.2 (A), SW22.2
unnamed: D23.2 (A), SW23.2
unnamed: D24.2 (A), SW24.2
unnamed: D25.2 (A), SW25.2
unnamed: D26.2 (A), SW26.2
unnamed: D27.2 (A), SW27.2
unnamed: D28.2 (A), SW28.2
unnamed: D29.2 (A), SW29.2
unnamed: D30.2 (A), SW30.2
unnamed: D31.2 (A), SW31.2
unnamed: D32.2 (A), SW32.2
unnamed: D33.2 (A), SW33.2
unnamed: D34.2 (A), SW34.2
unnamed: D35.2 (A), SW35.2
unnamed: D36.2 (A), SW36.2
unnamed: D37.2 (A), SW37.2
unnamed: D38.2 (A), SW38.2
unnamed: D39.2 (A), SW39.2
unnamed: D40.2 (A), SW40.2
unnamed: D41.2 (A), SW41.2
unnamed: D42.2 (A), SW42.2
unnamed: D43.2 (A), SW43.2
unnamed: D44.2 (A), SW44.2
unnamed: D45.2 (A), SW45.2
unnamed: D46.2 (A), SW46.2
unnamed: D47.2 (A), SW47.2
unnamed: D48.2 (A), SW48.2
unnamed: D49.2 (A), SW49.2
unnamed: D50.2 (A), SW50.2
unnamed: D51.2 (A), SW51.2
unnamed: D52.2 (A), SW52.2
unnamed: D53.2 (A), SW53.2
unnamed: D54.2 (A), SW54.2
unnamed: D55.2 (A), SW55.2
unnamed: D56.2 (A), SW56.2
unnamed: D57.2 (A), SW57.2
unnamed: D58.2 (A), SW58.2
unnamed: D59.2 (A), SW59.2
unnamed: D60.2 (A), SW60.2
unnamed: D61.2 (A), SW61.2
R0: A1.4 (GPIO2), D1.1 (K), D2.1 (K), D3.1 (K), D4.1 (K), D5.1 (K), D6.1 (K), D7.1 (K), D8.1 (K), D9.1 (K), D10.1 (K), D11.1 (K), D12.1 (K), D13.1 (K), D14.1 (K)
R1: A1.5 (GPIO3), D15.1 (K), D16.1 (K), D17.1 (K), D18.1 (K), D19.1 (K), D20.1 (K), D21.1 (K), D22.1 (K), D23.1 (K), D24.1 (K), D25.1 (K), D26.1 (K), D27.1 (K), D28.1 (K)
R2: A1.6 (GPIO4), D29.1 (K), D30.1 (K), D31.1 (K), D32.1 (K), D33.1 (K), D34.1 (K), D35.1 (K), D36.1 (K), D37.1 (K), D38.1 (K), D39.1 (K), D40.1 (K), D41.1 (K)
R3: A1.7 (GPIO5), D50.1 (K), D51.1 (K), D52.1 (K), D53.1 (K), D54.1 (K), D55.1 (K), D56.1 (K), D57.1 (K), D58.1 (K), D59.1 (K), D60.1 (K), D61.1 (K)
R4: A1.9 (GPIO6), D42.1 (K), D43.1 (K), D44.1 (K), D45.1 (K), D46.1 (K), D47.1 (K), D48.1 (K), D49.1 (K)
S1: A1.31 (GPIO26_ADC0), SW62.S1
S2: A1.2 (GPIO1), SW63.S1



Board: 2 copper layers, 321.0 x 101.0 mm, 130 parts (61 on the bottom side), 88 nets.

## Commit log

2026-09-23 Add MOSFET amplifier project overview
2026-09-23 Add MOSFET amplifier project
    [ELE404Project.kicad_pcb, ELE404Project.kicad_sch]
2026-09-23 Add reproducible ngspice study, package CI, and v0.2.0 release tools
    [baseline-ac-loaded.csv, baseline-ac-unloaded.csv, baseline-transient.csv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]
2026-11-05 docs: tighten README wording and update checksum
    Claude-Session: https://claude.ai/code/session_01XiaE12VeFwEqwoQMNhFaJo
